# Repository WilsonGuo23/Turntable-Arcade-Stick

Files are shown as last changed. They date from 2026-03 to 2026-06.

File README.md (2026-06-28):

# Turntable Arcade Stick
arcade stick

## What is this?

The turntable arcade stick is an arcade stick design that is 3D printable and is printed piecewise, making it highly customizable. 
The movement side panel (traditionally on the left) can be rotated and locked in place to allow the hands to be placed at a more comfortable angle than traditional arcade stick panels.
This design also has an easily removable panel on the bottom to service common issues in between rounds like loose buttons or disconnected wiring.

## Parts Required for Assembly

- X8 45mm M3 Countersunk Screws

- X4 20mm M3 Countersunk Screws

- X14 M3 Bolts

- Microcontroller or Fighting board PCB of choice

- Wiring Harness (if using fighting board PCB)

  > *Note:* You can make your own wiring harness by crimping female spade connectors to your wiring. I like kits like
  *[these](https://www.amazon.com/Feggizuli-Connectors-Insulating-Terminals-Electrical/dp/B0CJQ8PN7P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)* because options are nice to have

- X5 24mm Screw on Button

- Required Printables

  1. Turntable Right Panel

  2. Turntable Left Panel
 
  3. Turntable Front Panel
 
  4. Turntable Back Panel
 
  5. Turntable Movement Panel
 
  6. Quick Remove Bottom Panel
 
> **Important Note:** Your panel choices will change what hardware you should be buying. Relevant parts are noted beneath the panel file name
 
- Movement Side Printables (Pick One)

     1. Turntable Panel for Joystick
 
        - Joystick

     3. Turntable Panel for Stickless
 
        -  X1 30mm Screw on Button
        -  X3 24mm Screw on Button
 
- Button Side Printables (Pick One)
  
     1. Wilson's Preferred Button Layout Panel
 
        - X8 30mm Screw on Buttons
       
> *Note:* The panels included in the "Pick One" sections are easily swapped so it is possible to make each panel a module if you would like to have 1 enclosure that does everything and can be changed within a minute

## How to Assemble

  1. Connect the left, right, front, and back panels such that they form a square.

> *Note:* The left and right panels can be on either side, there's no actual reason for one to be on one side or the other in V1.

  2. Place nuts in the hexagonal hole on the bottom of the 4 side panels.

  3. Use the M3x45mm screws to mount the turntable movement panel and the button panel to the top of the 4 side panels with the indents facing up.

  4. Place your turntable panel in the circular indent in the turntable movement panel with the indents facing up.

  5. Install your buttons, USB passthrough, and joystick (if using joystick).

  6. Wire the installed electronics to your microcontroller/fighting board PCB.

  7. Glue 2 magnets to the indents in the bottom panel and the indents in the left panel,then leave the indents exposed in the open to dry.

  8. Slide the bottom panel to close the arcade stick.

Example internal for arcade stick

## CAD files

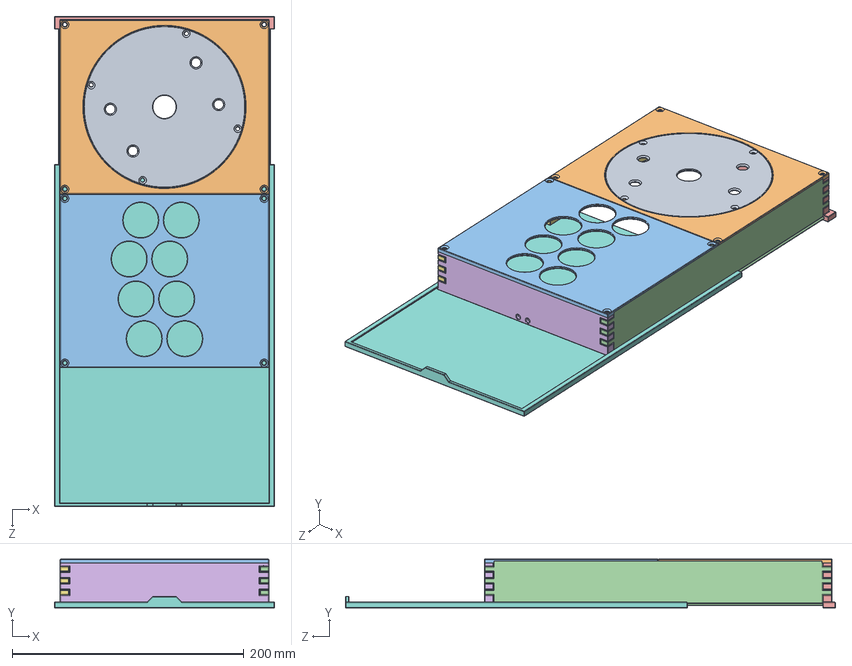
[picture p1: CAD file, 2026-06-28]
V2/Turntable Stick Assembly.SLDASM
190.0 x 42.3 x 422.8 mm
Quick Remove Bottom Panel
Turntable Front Panel
Turntable Left Panel
Turntable Right Panel
Turntable Back Panel
Wilson's Preferred Button Layout Panel
Turntable Movement Panel
Turntable Panel For Joystick

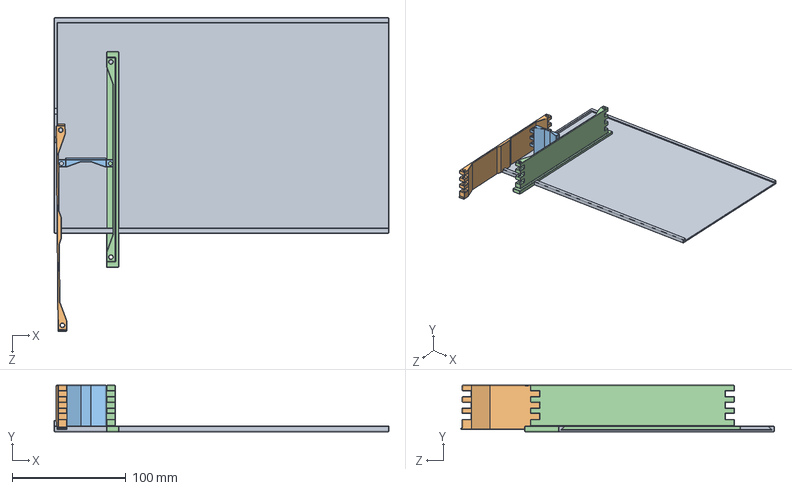
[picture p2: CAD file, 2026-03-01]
V2/Turntable Stick Assembly Test.SLDASM
295.1 x 41.0 x 276.4 mm
Turntable Right Panel
Turntable Front Panel Test
Turntable Left Panel
Quick Remove Bottom Panel

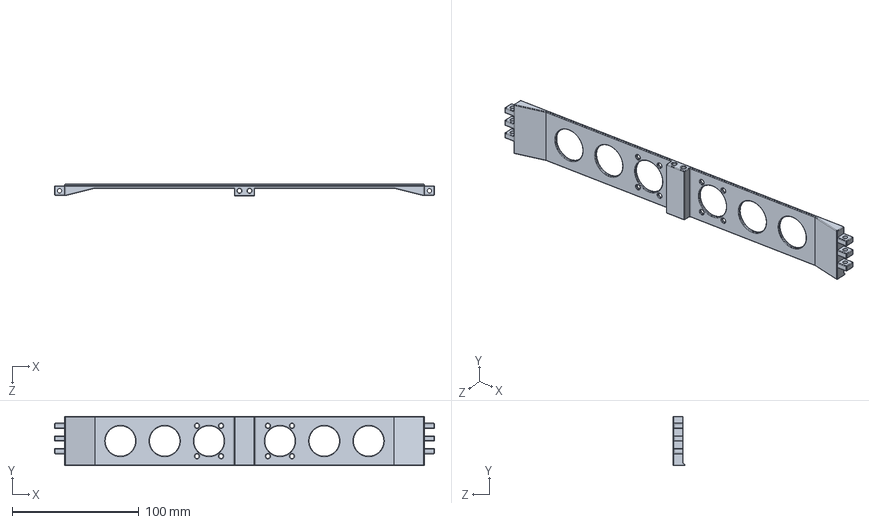
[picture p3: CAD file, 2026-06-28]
V2/Turntable Front Panel.SLDPRT
300.0 x 39.0 x 9.29 mm

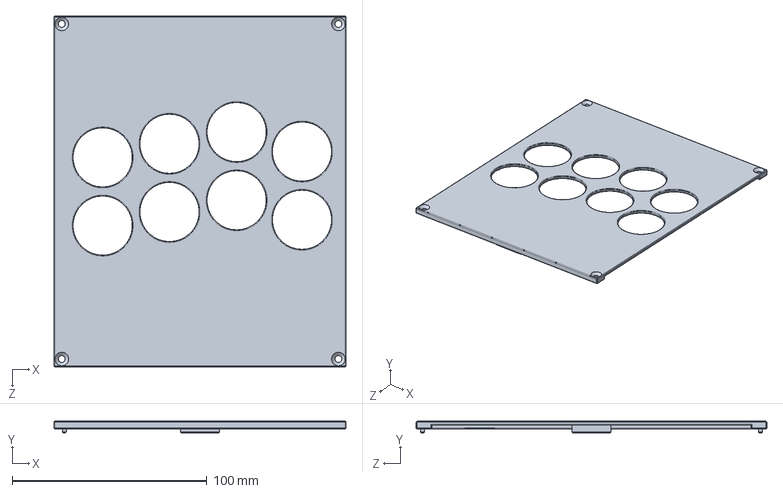
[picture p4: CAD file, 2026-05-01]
V2/Wilson's Preferred Button Layout Panel.SLDPRT
149.9 x 6.00 x 180.0 mm

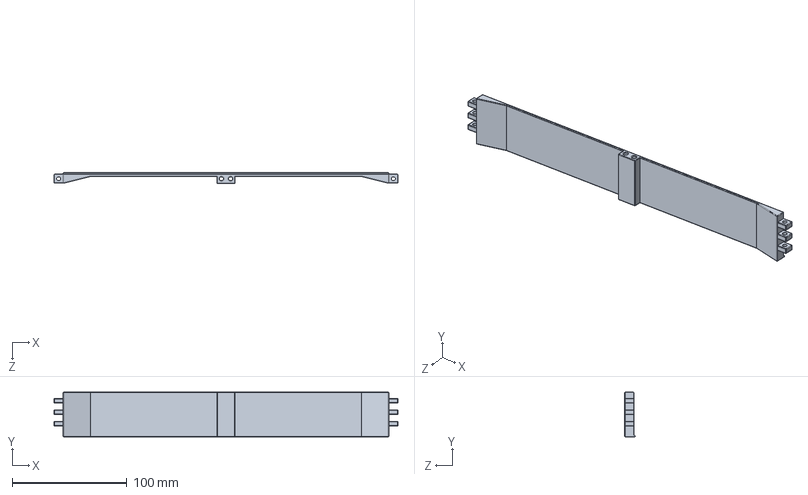
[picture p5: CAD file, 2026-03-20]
V2/Turntable Back Panel.SLDPRT
300.0 x 39.0 x 9.29 mm

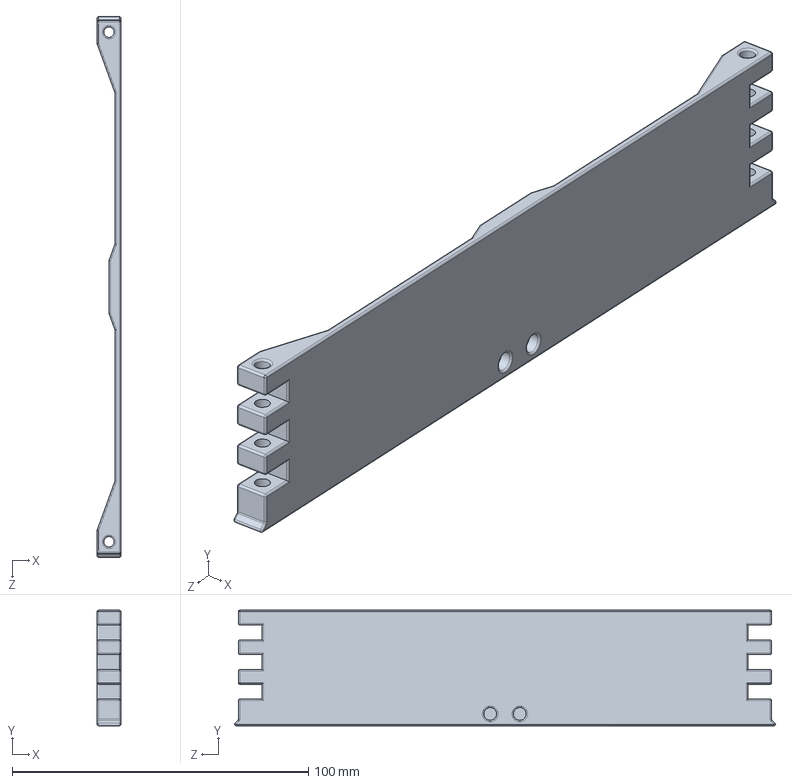
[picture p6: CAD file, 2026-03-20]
V2/Turntable Left Panel.SLDPRT
8.00 x 39.0 x 182.6 mm

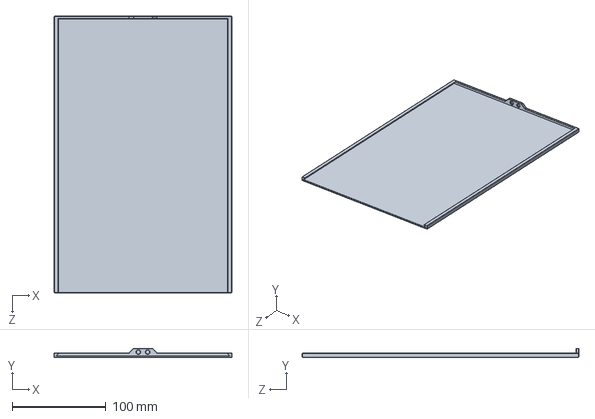
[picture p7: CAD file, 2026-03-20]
V2/Quick Remove Bottom Panel.SLDPRT
190.0 x 10.0 x 295.1 mm

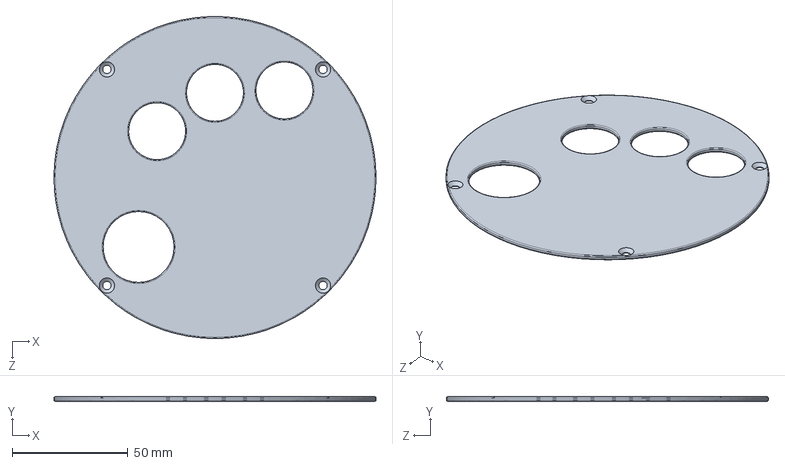
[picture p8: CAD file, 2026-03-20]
V2/Turntable Panel For Stickless.SLDPRT
139.1 x 2.00 x 139.1 mm

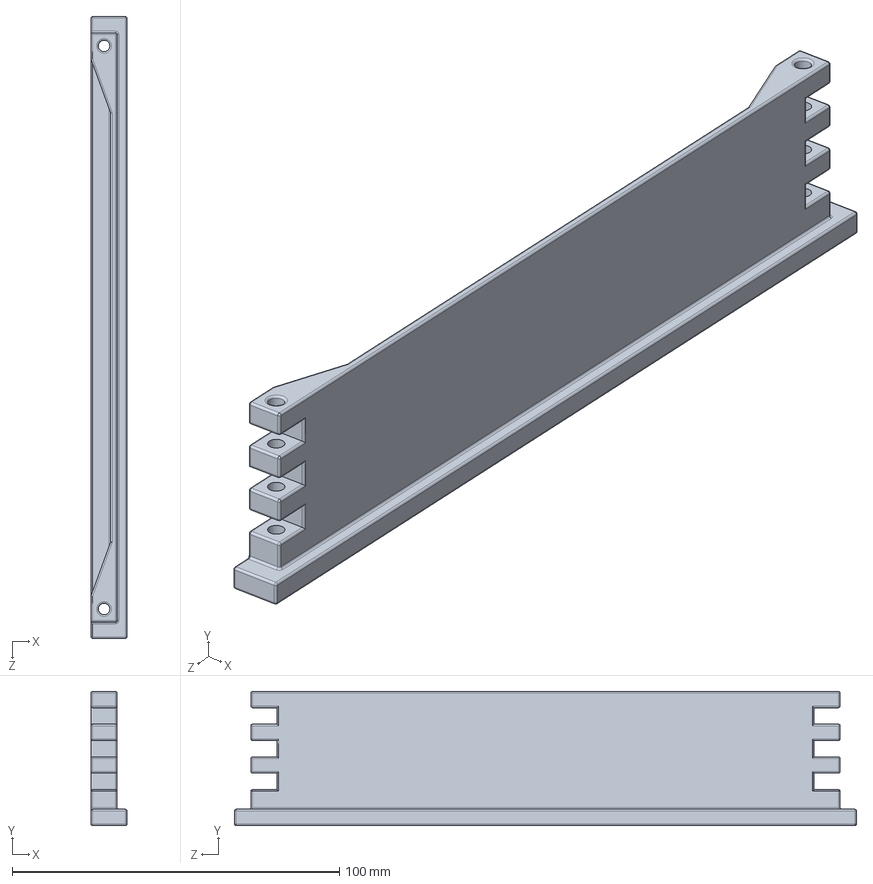
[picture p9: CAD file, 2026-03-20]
V2/Turntable Right Panel.SLDPRT
11.0 x 41.0 x 190.0 mm

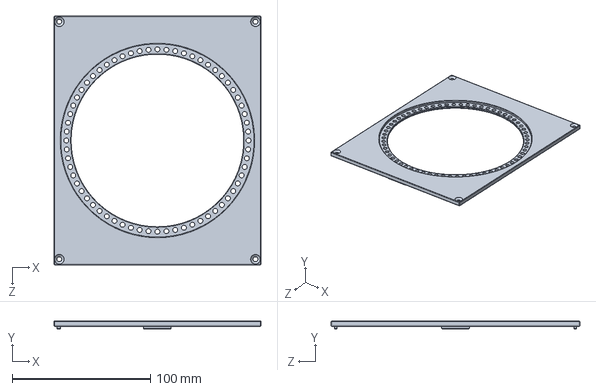
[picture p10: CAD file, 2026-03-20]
V2/Turntable Movement Panel.SLDPRT
149.9 x 6.00 x 180.0 mm

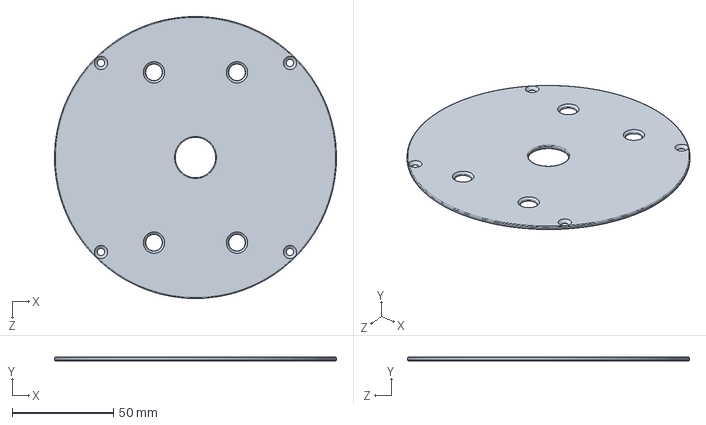
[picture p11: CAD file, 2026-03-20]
V2/Turntable Panel For Joystick.SLDPRT
139.3 x 1.90 x 139.3 mm

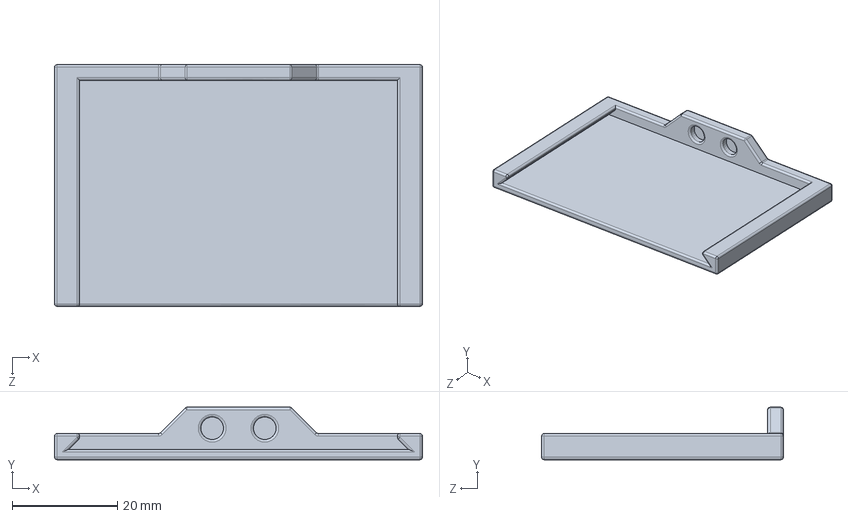
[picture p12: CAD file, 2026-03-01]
V2/Quick Remove Bottom Panel Test.SLDPRT
70.0 x 10.0 x 46.0 mm

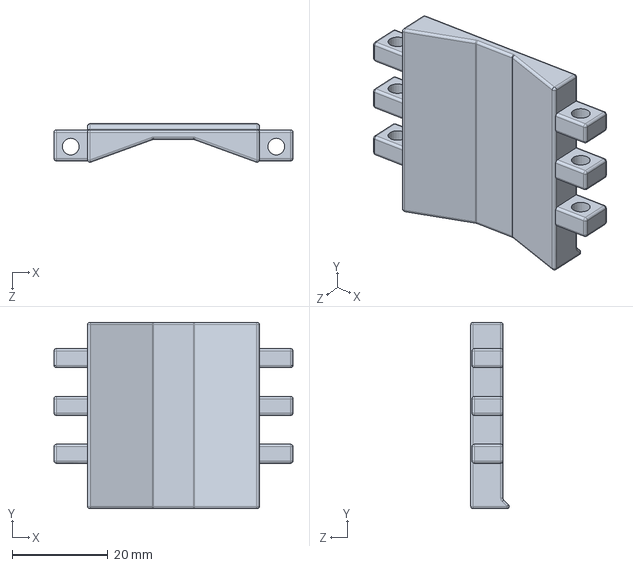
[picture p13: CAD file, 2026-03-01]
V2/Turntable Front Panel Test.SLDPRT
50.0 x 39.0 x 8.08 mm

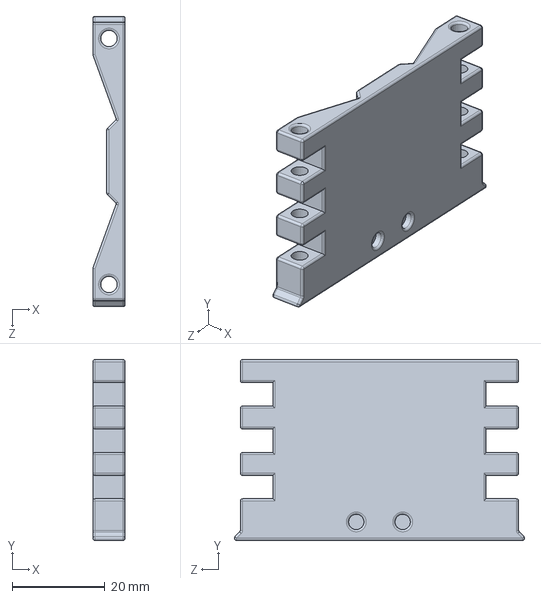
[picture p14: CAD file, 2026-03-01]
V2/Turntable Left Panel Test.SLDPRT
7.00 x 39.0 x 62.6 mm

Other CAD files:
V2/Turntable Right Panel Test.SLDPRT
V2/Button Panel Classic.SLDPRT
V1/Turntable Stick Assembly.SLDASM
V1/Wilson's Preferred Button Layout Panel.SLDPRT
V1/Quick Remove Bottom Panel.SLDPRT
V1/Turntable Back Panel.SLDPRT
V1/Turntable Front Panel.SLDPRT
V1/Turntable Left Panel.SLDPRT
V1/Turntable Movement Panel.SLDPRT
V1/Turntable Panel For Joystick.SLDPRT
V1/Turntable Panel For Stickless.SLDPRT
V1/Turntable Right Panel.SLDPRT
V2 STL Files/Quick Remove Bottom Panel.STL
V2 STL Files/Turntable Back Panel.STL
V2 STL Files/Turntable Front Panel.STL
V2 STL Files/Turntable Left Panel.STL
V2 STL Files/Turntable Movement Panel.STL
V2 STL Files/Turntable Panel For Joystick.STL
V2 STL Files/Turntable Panel For Stickless.STL
V2 STL Files/Turntable Right Panel.STL
V2 STL Files/Wilson's Preferred Button Layout Panel.STL

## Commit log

2026-03-01 Adding V1 Work
    see title
    [Button Panel Classic.SLDPRT, Quick Remove Bottom Panel Test.SLDPRT, Quick Remove Bottom Panel.SLDPRT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]
2026-03-01 Separating files from V1 to make room for V2
    [Button Panel Classic.SLDPRT, Quick Remove Bottom Panel Test.SLDPRT, Quick Remove Bottom Panel.SLDPRT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]
2026-03-06 Create README with assembly instructions and parts list
    Added detailed assembly instructions and parts list for the turntable arcade stick.
2026-03-13 Enhance README with assembly steps and images
    Added images and detailed assembly instructions for the turntable arcade stick.
2026-03-20 V2 1st draft finished
    made changes to v2 design, not sure if it all fits yet, will test
    [Button Panel Classic.SLDPRT, Quick Remove Bottom Panel Test.SLDPRT, Quick Remove Bottom Panel.SLDPRT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]
2026-05-01 consistency update
    updated button panel to account for left wall size increase
    [Turntable Stick Assembly.SLDASM, Wilson's Preferred Button Layout Panel.SLDPRT, Wilson's Preferred Button Layout Panel.STL]
2026-06-28 Update front panel
    Added mounting holes for tournament lockout switch
    [Turntable Front Panel.SLDPRT, Turntable Front Panel.STL, Turntable Stick Assembly.SLDASM]
